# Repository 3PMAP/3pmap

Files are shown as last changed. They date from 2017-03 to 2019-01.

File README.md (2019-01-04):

## 3d Printed Myoelectric Arm Prosthetic

<div align="center">
  
</div>

Final school research project at [Ds. Pierson College](https://github.com/Piersoncollege).

By [Yochem van Rosmalen](@yochem), [Jelle van Bost](@jelle641) and [Nathan Guirado](@NathGui).

## Schematics
The electronic schemes for the project can be found at the folder [`Schematics`](/Schematics/). This folder includes the overall schematics for the project aswell as the self designed and `PCB`.

## 3D-Designs
The designs are open-source available, too! You can find them in another [repository](https://github.com/3pmap/3dprints) on this organisation page.

## Paper
The subject is also precisely described in a paper. This paper is available to the public on Github [here](https://github.com/3PMAP/profielwerkstuk/blob/master/prothesehand.pdf) (dutch).

## License
Provided under the [MIT license](https://www.github.com/3PMAP/3pmap/blob/master/LICENSE).

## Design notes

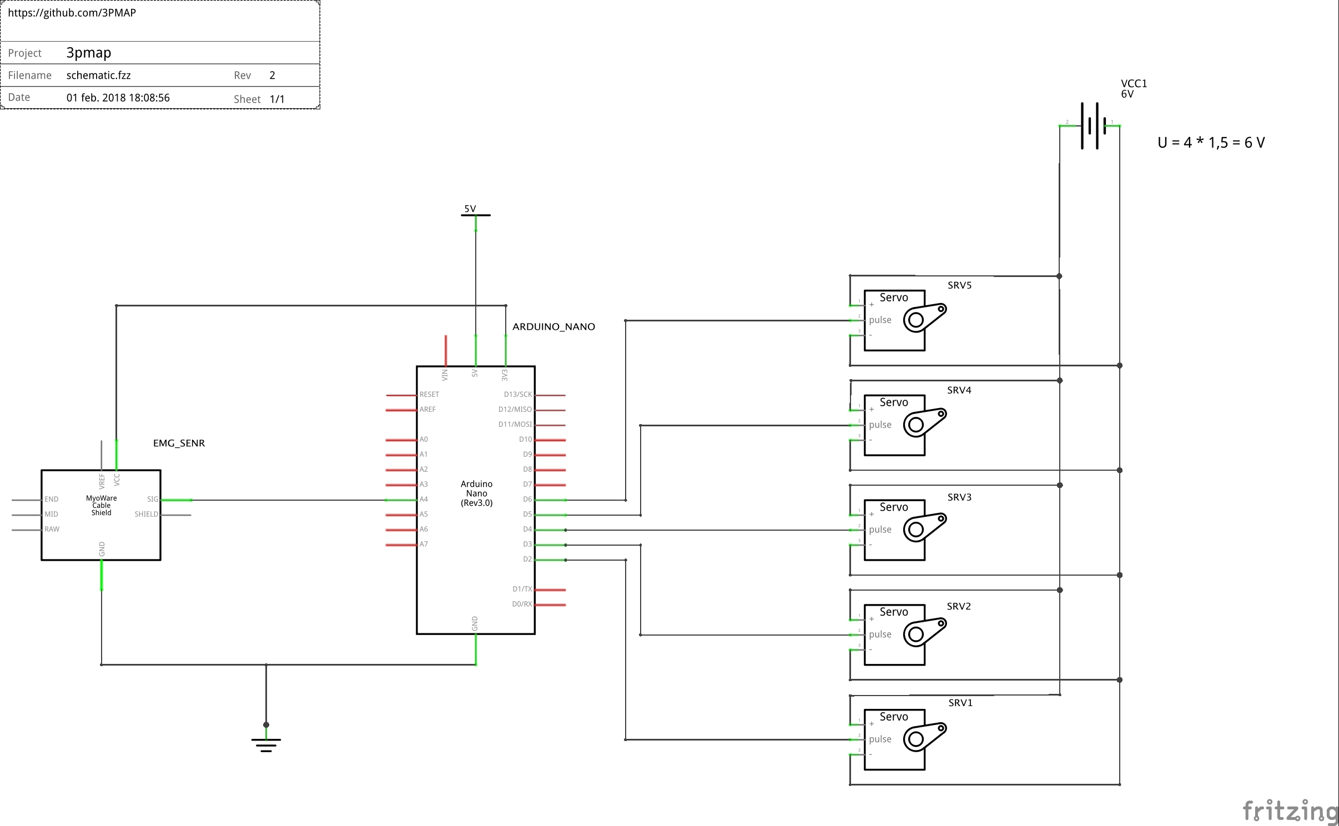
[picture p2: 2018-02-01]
Schematics/schematic.jpg

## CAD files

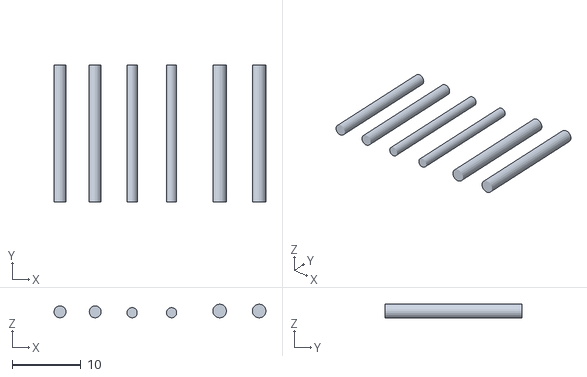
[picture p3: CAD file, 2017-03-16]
docs/3dPrints/pin.stl
30.9 x 20.0 x 2.00

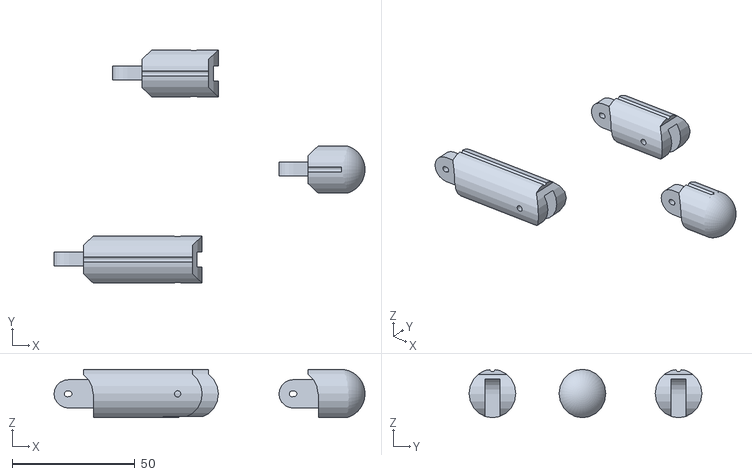
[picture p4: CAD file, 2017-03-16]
docs/3dPrints/printdocument.stl
126.5 x 94.7 x 19.7

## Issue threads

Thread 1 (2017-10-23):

Gebruik (besturing) van de hand

yochem, 2017-10-23:
# **Hoe gaan we de hand aansturen?**

Hier een aantal ideeën (voeg gerust meer toe):

### Keypad membraan
**Voordelen**: Hebben we al liggen, makkelijk in gebruik, dun
**Nadelen**: Gebruikt veel pins (misschien manier om dat te voorkomen?), andere hand nodig voor aansturing, niet erg gebruiksvriendelijk

### Zenuwen
Ziet er super leip uit, maar vraag me af of dit haalbaar is. Erg sensitieve connectoren nodig en veel onderzoek doen naar welke zenuw welke spier aanstuurt.

### Spieren
Aangezien de gebruiker wel nog zijn arm heeft, kunnen we de armspieren gebruiken voor het besturen van de motortjes. Dit door de druk van de twee lange armspieren te meten (in deelvraag 2.2 staat dat een beetje uitgewerkt onder het kopje spieren).

### Via wifi / bluetooth
Dus via een **app** of via de **computer**. Zouden we verder uit kunnen werken.

yochem, 2017-12-28:
dmv sparkfuns [MyoWare Muscle Sensor](https://www.sparkfun.com/products/13723)

Closed 2018-02-01.

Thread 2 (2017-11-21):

Motor niet achteruit

jelle641, 2017-11-21:
Motor draait maar 1 kant op

jelle641, 2017-11-21:
/*
 Stepper.cpp - - Stepper library for Wiring/Arduino - Version 0.4

 Original library     (0.1) by Tom Igoe.
 Two-wire modifications   (0.2) by Sebastian Gassner
 Combination version   (0.3) by Tom Igoe and David Mellis
 Bug fix for four-wire   (0.4) by Tom Igoe, bug fix from Noah Shibley
 Add Half Step mode      (0.5) by D Traynor

 Drives a unipolar or bipolar stepper motor using  2 wires or 4 wires

 The sequence for full step of control signals for 4 control wires is as follows:
 # Modified from the original 1010, 0110, 0101, 1001 - since my motor would not reverse

 Step C0 C1 C2 C3
    1  0  0  1  1
    2  1  0  0  1
    3  1  1  0  0
    4  0  1  1  0

 The sequence for halfstep for 4 control wires is as follows:
 # Added this 8 step sequence for halfstep control (v0.5)

 Step C0 C1 C2 C3
    1  1  0  0  1
    2  1  0  0  0
    3  1  1  0  0
    4  0  1  0  0
    5  0  1  1  0
    6  0  0  1  0
    7  0  0  1  1
    8  0  0  0  1

 The sequence of controls signals for 2 control wires is as follows
 (columns C1 and C2 from above):

 Step C0 C1
    1  0  1
    2  1  1
    3  1  0
    4  0  0

 The circuits can be found at

http://www.arduino.cc/en/Tutorial/Stepper
*/

#include "Arduino.h"
#include "Stepper.h"

/*two-wire constructor.
* Sets which wires should control the motor.
*/
Stepper::Stepper(int number_of_steps, int motor_pin_1, int motor_pin_2, int mod_count)
{
 this->step_number = 0;      // which step the motor is on
 this->speed = 0;        // the motor speed, in revolutions per minute
 this->direction = 0;      // motor direction
 this->last_step_time = 0;    // time stamp in ms of the last step taken
 this->number_of_steps = number_of_steps;    // total number of steps for this motor
 this->mod_count = 4;      // default number of steps in a sequence (v0.5)

 // Arduino pins for the motor control connection:
 this->motor_pin_1 = motor_pin_1;
 this->motor_pin_2 = motor_pin_2;

 // setup the pins on the microcontroller:
 pinMode(this->motor_pin_1, OUTPUT);
 pinMode(this->motor_pin_2, OUTPUT);

 // modulo count is the No of control steps in a motor STEP sequence (v0.5)
 this->mod_count = mod_count;

 // When there are only 2 pins, set the other two to 0:
 this->motor_pin_3 = 0;
 this->motor_pin_4 = 0;

 // pin_count is used by the stepMotor() method:
 this->pin_count = 2;
}

/*   constructor for four-pin version at FULL step
*   Sets which wires should control the motor.
*   New parameter 'mod_count' to cater for halfstep sequence (v0.5)
*/

Stepper::Stepper(int number_of_steps, int motor_pin_1, int motor_pin_2, int motor_pin_3, int motor_pin_4, int mod_count)
{
 this->step_number = 0;      // which step the motor is on
 this->speed = 0;        // the motor speed, in revolutions per minute
 this->direction = 0;      // motor direction
 this->last_step_time = 0;    // time stamp in ms of the last step taken
 this->number_of_steps = number_of_steps;    // total number of steps for this motor
 this->mod_count = 4;      // default number of steps  FULL STEP = 4 whilst HALF STEP = 8 (v0.5)

 // Arduino pins for the motor control connection:
 this->motor_pin_1 = motor_pin_1;
 this->motor_pin_2 = motor_pin_2;
 this->motor_pin_3 = motor_pin_3;
 this->motor_pin_4 = motor_pin_4;

 // modulo count is the No of control steps in a motor STEP
 this->mod_count = mod_count;

 // setup the pins on the microcontroller:
 pinMode(this->motor_pin_1, OUTPUT);
 pinMode(this->motor_pin_2, OUTPUT);
 pinMode(this->motor_pin_3, OUTPUT);
 pinMode(this->motor_pin_4, OUTPUT);

 // pin_count is used by the stepMotor() method:
 this->pin_count = 4;
}

/*
 Sets the speed in revs per minute
 Added a safeguard minimum delay of 2mS, may vary for other motors
*/
void Stepper::setSpeed(long whatSpeed)
{
 this->step_delay = 60L * 1000L / this->number_of_steps / whatSpeed;
 if (this->step_delay < 2) {
   this->step_delay = 2;    // if the delay is too small then the motor will stall (v0.5)
 }
}

/*
 Moves the motor steps_to_move steps.  If the number is negative,
  the motor moves in the reverse direction.
  Had to change the step sequence to get my motor [28BYJ-48] to reverse in full step (v0.5)
*/
void Stepper::step(int steps_to_move)
{
 int steps_left = abs(steps_to_move);  // how many steps to take

 // determine direction based on whether steps_to_mode is + or -:
 if (steps_to_move > 0) {this->direction = 1;}
 if (steps_to_move < 0) {this->direction = 0;}

 // decrement the number of steps, moving one step each time:
 while(steps_left > 0) {
 // move only if the appropriate delay has passed:
 if (millis() - this->last_step_time >= this->step_delay) {
     // get the timeStamp of when you stepped:
     this->last_step_time = millis();
     // increment or decrement the step number,
     // depending on direction:
     if (this->direction == 1) {
       this->step_number++;
       if (this->step_number == this->number_of_steps) {
         this->step_number = 0;
       }
     }
     else {
       if (this->step_number == 0) {
         this->step_number = this->number_of_steps;
       }
       this->step_number--;
     }
     // decrement the steps left:
     steps_left--;
     // step the motor to step number 0, 1, 2, or 3:
     // or 4,5,6,7 for HALFSTEP mode (v0.5)
     stepMotor(this->step_number % this->mod_count);
   }
 }
}

/*
* Moves the motor forward or backwards.
*/
void Stepper::stepMotor(int thisStep)
{
 if (this->pin_count == 2) {       // 3 parts of the IF are mutually exclusive -> hence the addition of the ELSE
   switch (thisStep) {
     case 0: /* 01 */
     digitalWrite(motor_pin_1, LOW);
     digitalWrite(motor_pin_2, HIGH);
     break;
     case 1: /* 11 */
     digitalWrite(motor_pin_1, HIGH);
     digitalWrite(motor_pin_2, HIGH);
     break;
     case 2: /* 10 */
     digitalWrite(motor_pin_1, HIGH);
     digitalWrite(motor_pin_2, LOW);
     break;
     case 3: /* 00 */
     digitalWrite(motor_pin_1, LOW);
     digitalWrite(motor_pin_2, LOW);
     break;
   }
 } else if (this->pin_count == 4 && this->mod_count == 4) {    // (v0.5) allows distinction between full and half step
   switch (thisStep) {
     case 0:    // 0011
     digitalWrite(motor_pin_1, LOW);
     digitalWrite(motor_pin_2, LOW);
     digitalWrite(motor_pin_3, HIGH);
     digitalWrite(motor_pin_4, HIGH);
     break;
     case 1:    // 1001
     digitalWrite(motor_pin_1, HIGH);
     digitalWrite(motor_pin_2, LOW);
     digitalWrite(motor_pin_3, LOW);
     digitalWrite(motor_pin_4, HIGH);
     break;
     case 2:    // 1100
     digitalWrite(motor_pin_1, HIGH);
     digitalWrite(motor_pin_2, HIGH);
     digitalWrite(motor_pin_3, LOW);
     digitalWrite(motor_pin_4, LOW);
     break;
     case 3:    // 0110
     digitalWrite(motor_pin_1, LOW);
     digitalWrite(motor_pin_2, HIGH);
     digitalWrite(motor_pin_3, HIGH);
     digitalWrite(motor_pin_4, LOW);
     break;
   }
 } else if (this->pin_count == 4 && this->mod_count == 8) {    //(v0.5)
   switch (thisStep) {
     case 0:    //1001
     digitalWrite(motor_pin_1, HIGH);
     digitalWrite(motor_pin_2, LOW);
     digitalWrite(motor_pin_3, LOW);
     digitalWrite(motor_pin_4, HIGH);
     break;
     case 1:    //1000
     digitalWrite(motor_pin_1, HIGH);
     digitalWrite(motor_pin_2, LOW);
     digitalWrite(motor_pin_3, LOW);
     digitalWrite(motor_pin_4, LOW);
     break;
     case 2:    //1100
     digitalWrite(motor_pin_1, HIGH);
     digitalWrite(motor_pin_2, HIGH);
     digitalWrite(motor_pin_3, LOW);
     digitalWrite(motor_pin_4, LOW);
     break;
     case 3:    //0100
     digitalWrite(motor_pin_1, LOW);
     digitalWrite(motor_pin_2, HIGH);
     digitalWrite(motor_pin_3, LOW);
     digitalWrite(motor_pin_4, LOW);
     break;
     case 4:    //0110
     digitalWrite(motor_pin_1, LOW);
     digitalWrite(motor_pin_2, HIGH);
     digitalWrite(motor_pin_3, HIGH);
     digitalWrite(motor_pin_4, LOW);
     break;
     case 5:    //0010
     digitalWrite(motor_pin_1, LOW);
     digitalWrite(motor_pin_2, LOW);
     digitalWrite(motor_pin_3, HIGH);
     digitalWrite(motor_pin_4, LOW);
     break;
     case 6:    //0011
     digitalWrite(motor_pin_1, LOW);
     digitalWrite(motor_pin_2, LOW);
     digitalWrite(motor_pin_3, HIGH);
     digitalWrite(motor_pin_4, HIGH);
     break;
     case 7:    //0001
     digitalWrite(motor_pin_1, LOW);
     digitalWrite(motor_pin_2, LOW);
     digitalWrite(motor_pin_3, LOW);
     digitalWrite(motor_pin_4, HIGH);
     break;
   }
 }
}

/*
 version() returns the version of the library:
*/
int Stepper::version(void)
{
 return 5;
}

^Dat allemaal kopieren naar de library en dan zou het als het goed is wel lukken

yochem, 2017-11-22:
gefixt, zie PR #3

Closed 2017-11-22.

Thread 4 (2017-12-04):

Alle steppers aansluiten op ons Arduino Nano'tje

yochem, 2017-12-04:
De Nano heeft te weinig pins voor 5 motoren (4 pins per motor), dus zoekend naar een oplossing.

Dit [motor shield](https://www.martoparts.nl/l293_motorshield) gekocht, nu nog hier mee aan de slag.

yochem, 2017-12-18:
# OVERGANG OP SERVO MOTORS

Zie [servo branch](https://github.com/bionicarm/bionicarm/tree/servo). De servo motor heeft maar een signaalkabel (in vergelijking met 4 voor steppers), dus 5 servo's wordt geen probleem. Ze zijn nog niet binnen dus nog niet aan testen toegekomen. Als het blijkt te werken en het ook een vooruitgang voor de arm is push ik het

Closed 2018-02-01.

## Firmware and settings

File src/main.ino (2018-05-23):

// LIBRARIES //
#include <Servo.h>

// setting up servo's.
// m1 = finger 1 (thumb) etc.
Servo m1;
Servo m2;
Servo m3;
Servo m4;
Servo m5;


// SETUP //
void setup() {
	// Attach servo variables to digital pin 2-6
	m1.attach(2);
	m2.attach(3);
	m3.attach(4);
	m4.attach(5);
	m5.attach(6);

	// Serial monitor for debugging
	Serial.begin(9600);
}


// LOOP //
void loop() {
	// read the analog value of A4 and store it in variable 'emg'
	int emg = analogRead(A4);

	// if statement for defining which muscle activity corresponds
	// with which hand movement
	if (emg < 50) {
		allFingers(700);
	} else if (emg > 50 && emg < 200) {
		pinch();
	} else if (emg > 700) {
		allFingers(2300);
	}

	// delay to give the fingers time to move
	delay(1000);
}

// PRESETS //
void allFingers(int pos) {
	// get all fingers in same position.
	// With our servo's; 700 for open hand,
	// 2300 for fully closed hand
	m1.writeMicroseconds(pos);
	m2.writeMicroseconds(pos);
	m3.writeMicroseconds(pos);
	m4.writeMicroseconds(pos);
	m5.writeMicroseconds(pos);
	delay(100);
}

void pinch() {
	m1.writeMicroseconds(2300);
	m2.writeMicroseconds(2300);
	m3.writeMicroseconds(700);
	m4.writeMicroseconds(700);
	m5.writeMicroseconds(700);
	delay(100);
}

void thumbsUp() {
	m1.writeMicroseconds(700);
	m2.writeMicroseconds(2300);
	m3.writeMicroseconds(2300);
	m4.writeMicroseconds(2300);
	m5.writeMicroseconds(2300);
	delay(100);
}

void middleFinger() {
	m1.writeMicroseconds(2300);
	m2.writeMicroseconds(2300);
	m3.writeMicroseconds(700);
	m4.writeMicroseconds(2300);
	m5.writeMicroseconds(2300);
	delay(100);
}

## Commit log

2017-03-16 Added 3d Prints
    [pin.stl, printdocument.stl]
2017-04-04 Added a virtualenv and updated README
    [pin.stl, printdocument.stl]
2017-04-04 :gem: Now with a Jekyll project page!
    [pin.stl, printdocument.stl]
2017-04-04 Another update .gitignore
    _site won’t leave :angry:
2017-09-12 Moving to Arduino
    [pin.stl, printdocument.stl]
2017-10-01 removed jekyll docs and added schematics
    [FirstSetUp.fzz]
2017-10-02 Added Stepper lib
2017-10-02 Added schematics
    [FirstSetUp.fzz]
2017-10-05 Anotha one
    [FirstSetUp.fzz]
2017-10-05 Added 3dprints assets
    [fingerprototype.stl]
2017-10-05 Nieuw Fritzing schema
    Nieuw Fritzing schema met de kloppende ULN2003 chips. Alles komt nu
    overeen met de hardware die wij hebben. Draden nog niet verbonden
    [newparts.fzz]
2017-10-06 Now with custom fritzing parts
    [FirstSetUp.fzz]
2017-10-17 Update on Assets
    [FirstSetUp.fzz, newparts.fzz]
2017-10-17 Updated assets with new schem
    [firstworking.fzz]
2017-10-17 schematics can be found at the repo 'schematics'
    [FirstSetUp.fzz, fingerprototype.stl, firstworking.fzz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]
2017-11-22 Fixing issue #2
    Motor draait niet achteruit; waarschijnlijke fout in library
    [main.ino]
2017-12-03 Preparing for an Arduino with motor shield and multiple motors
2017-12-12 Various improvements
    New names for functions and variables:
    - changed `Finger1` etc to `Digit1` etc
    - changed `partRev` to `turnDigit` and it’s parameter `finger` to
    `digNum`
    - using `LED_BUILTIN` in stead of pin 13
    - started adding presets: `thumbsUp` and `pinch`
    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
2017-12-18 Rebuilt code from begin to work with servo motors
2017-12-18 Arduino voorbeeld
2018-01-11 added support sensor
2018-01-11 added a switch case and delays for presets
2018-01-27 analog pin
2018-02-01 Added schematic files to this repo
    3pmap/schematics might be deleted soon
    [schematic.fzz, servo_driver_pcb.fzz]
2018-02-01 Schematic folder added
    This folder might be deleted soon
    [schematic.fzz, servo_driver_pcb.fzz]
